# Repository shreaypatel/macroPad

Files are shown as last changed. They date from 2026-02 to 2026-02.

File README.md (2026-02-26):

This repository contains the relevant documentation for my custom macropad project. I designed this macropad to be slim, portable and minimalist to match my use case needs. I will primarily use it for onshape CAD shortcuts, 
but I am looking to explore setting up a different mode on it for KiCad shortcuts. The macropad connects to a computer via usb c. I began my design process with the wiring of the schematic. Here I opted for a 3x2 keyboard matrix 
to set up the switch connections. This takes up less input connections on the microcontroller while allowing me to customize 6 individual cherry mx switches. Next, I connected the diodes in between the switches to prevent keyboard
ghosting. Lastly, I set up a rotary rotary encoder switch for the zoom function on onshape CAD. This is the **CAD onshape source file (https://cad.onshape.com/documents/c0725aa56d0443495cbb7afd/w/927aa1fb6a4206026ca4e494/e/48b73c10d6aff836ede0c6ac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)**



With the schematic complete I moved onto routing the connections on the actual pcb. I also 
organized the layout of the pcb at this stage and ensured that all connections were wired up properly. 





With the elctrical side of things completed I moved onto desiging the 3D printed enclosure for the macropad. Here I built a minimalistic case with cutouts for the switches and rotary encoder switch. I also created a cutout for the USB C connection
port. Notably, I decided to forgo using screws to secure the top and bottom parts of the enclosure. Instead I opted for a press fit conneciton with 4 3D printed studs that connect directly to the top part of the case. These slot into a square shaped
hole in the bottom of the case. This makes the prototyping process easier and allows me to qucikly clean the internals of the macropad if need be. I applied a chamfer to the 4 studs to ensure they smoothly slot into the bottom of the case. I also included 
an elevated platform support for the pcb to rest on in the enclosure. Superglue can also be used to more securely attach the pins into their respective holes. 





This concludes my design process. Overall, I had a lot of fun making this project and I would say my favourite part was learning how to use KiCad to design PCBs for the first time. 

**BOM:**

* 1 x 3D printed case
* 1 x SEEED XIAO RP2040
* 4 x CHERRY MX keyswitches
* 1 x EC11 rotary encoder
* 6 x 1N4148 diodes

Final Image of CAD and electronics together: 


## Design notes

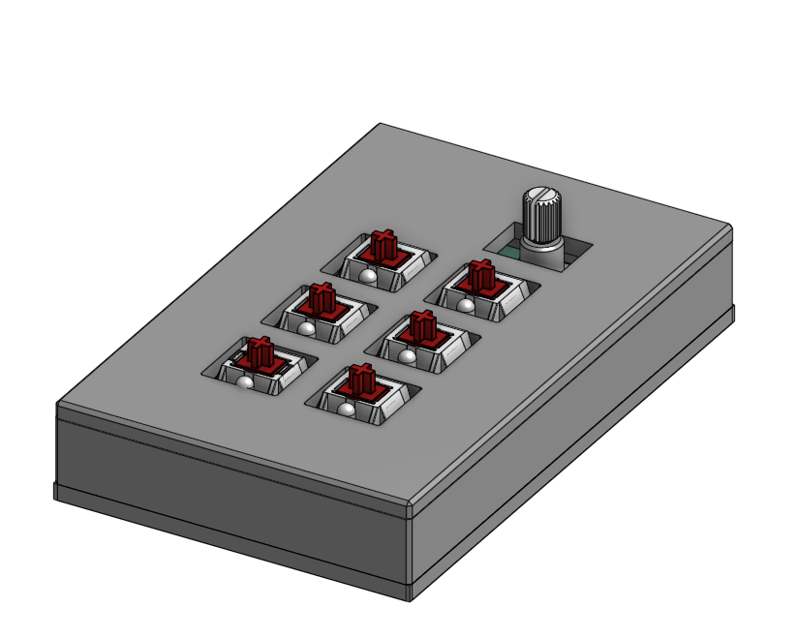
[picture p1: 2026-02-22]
CADwElectronics.png

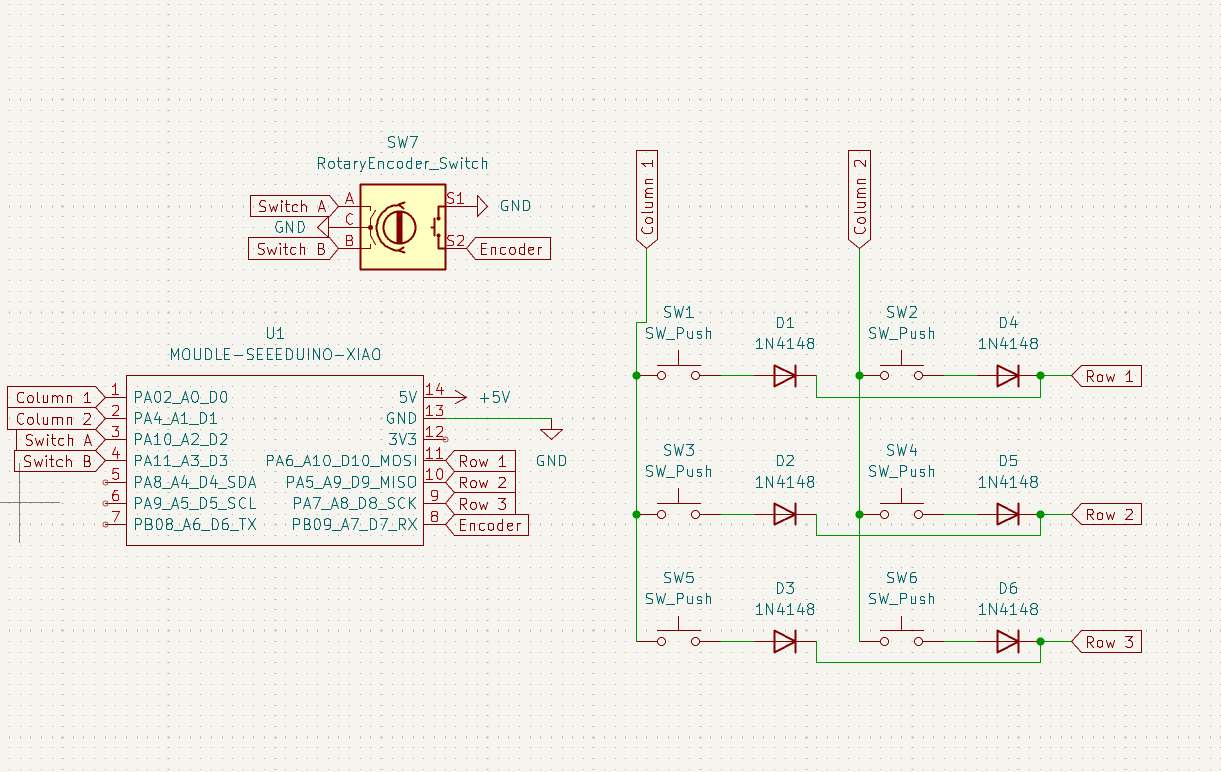
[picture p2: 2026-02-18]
PCB/schematicDrawingAngle1.png

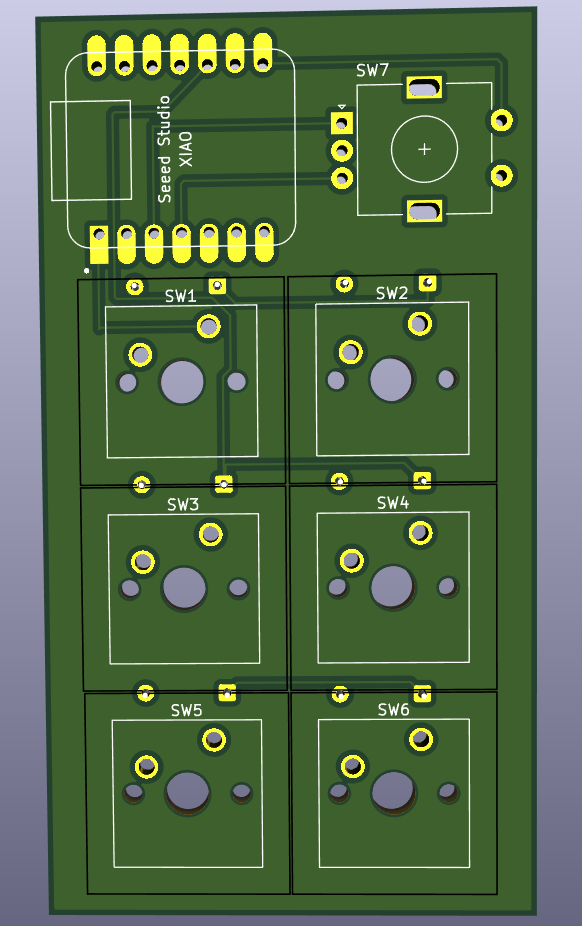
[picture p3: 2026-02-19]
PCB/pcb3dAngle_1.png

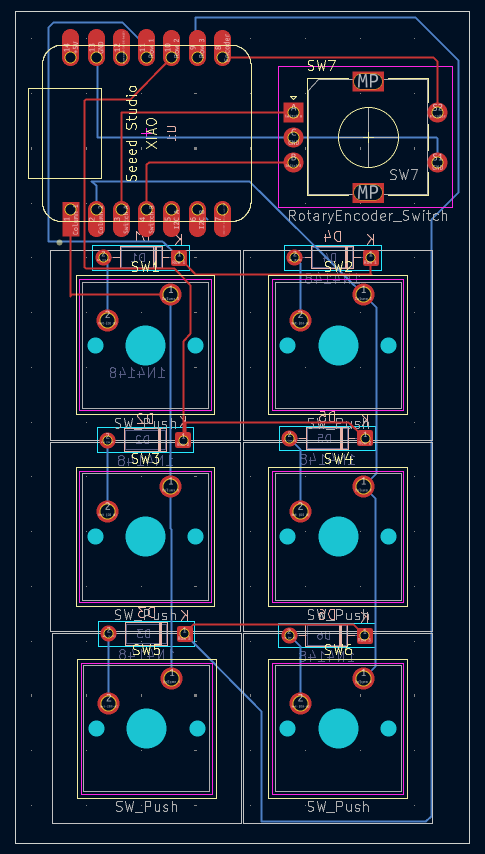
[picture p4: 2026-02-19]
PCB/pcb2dAngle1.png

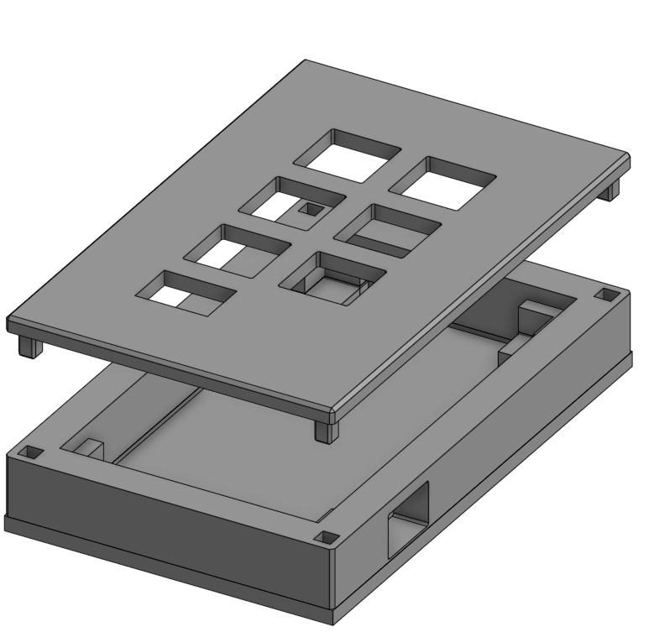
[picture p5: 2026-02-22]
CAD/mpAngle4.png

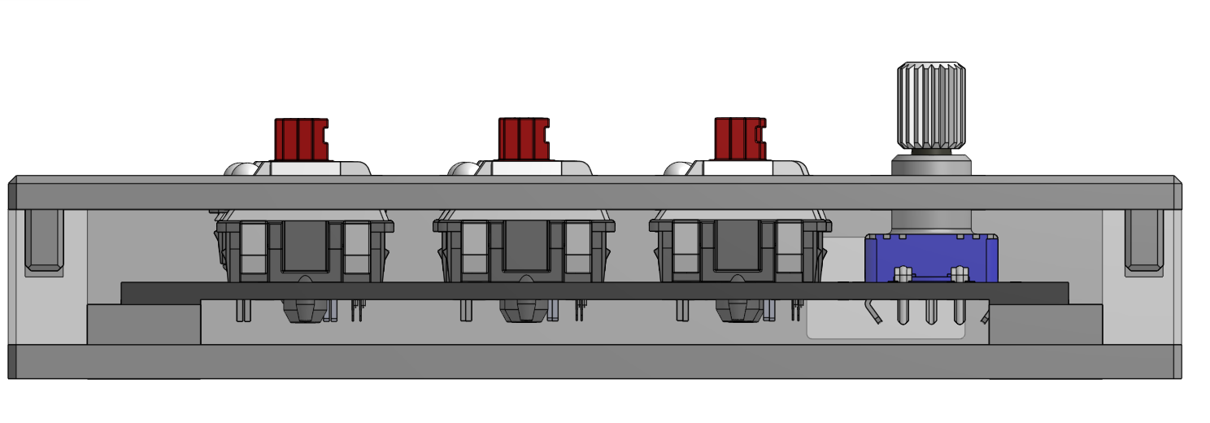
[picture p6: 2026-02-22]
CAD/mpAngle2.png

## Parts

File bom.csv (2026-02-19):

Designator | Footprint | Quantity | Value | LCSC Part #
D1, D2, D3, D4, D5, D6 | D_DO-35_SOD27_P7.62mm_Horizontal | 6 | 1N4148
SW1, SW2, SW3, SW4, SW5, SW6 | SW_Cherry_MX_1.00u_PCB | 6 | SW_Push
SW7 | RotaryEncoder_Alps_EC11E-Switch_Vertical_H20mm | 1 | RotaryEncoder_Switch
U1 | XIAO-Generic-Hybrid-14P-2.54-21X17.8MM | 1 | MOUDLE-SEEEDUINO-XIAO

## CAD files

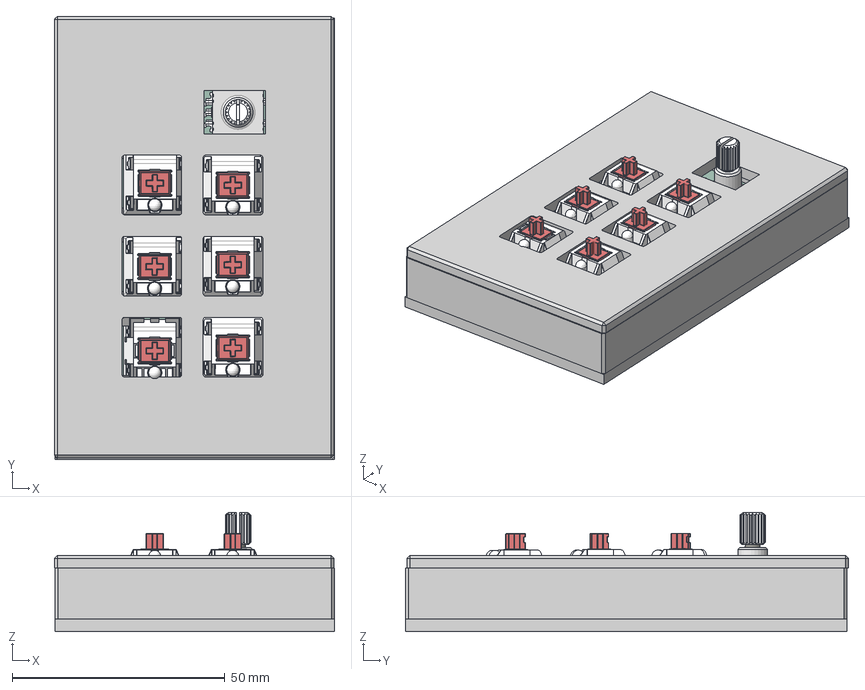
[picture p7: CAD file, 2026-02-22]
FullCADwElec.step
65.9 x 104.1 x 28.0 mm
Led 3mm_trans x 12
Pulsador x 6
Pin2 x 6
Pin1 x 6
Pieza5^Cherry MX x 6
��ת������EC11E-05SW
Bottom x 6
Top x 6
spMacropad_PCB

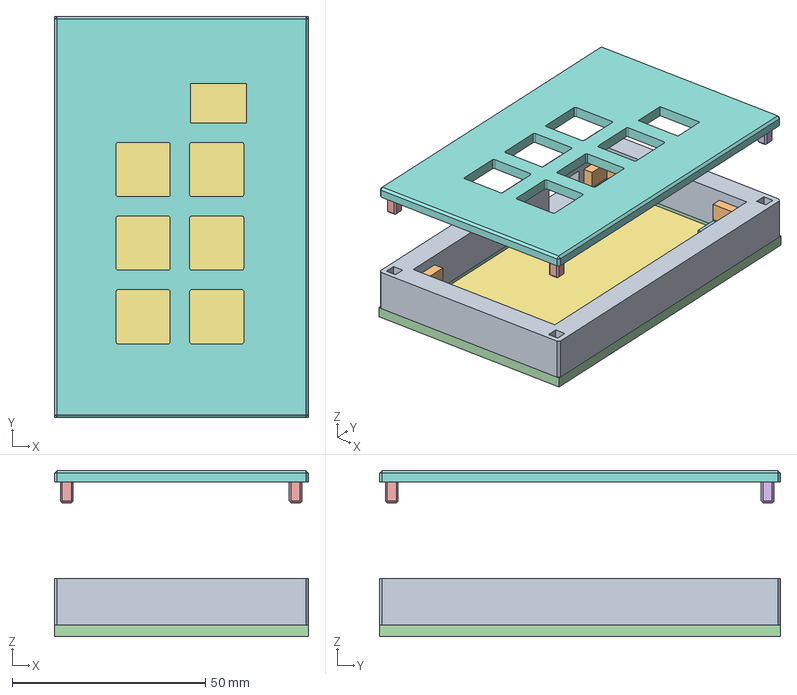
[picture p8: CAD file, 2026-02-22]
CAD/fullCoverCase.step
65.7 x 103.8 x 43.0 mm

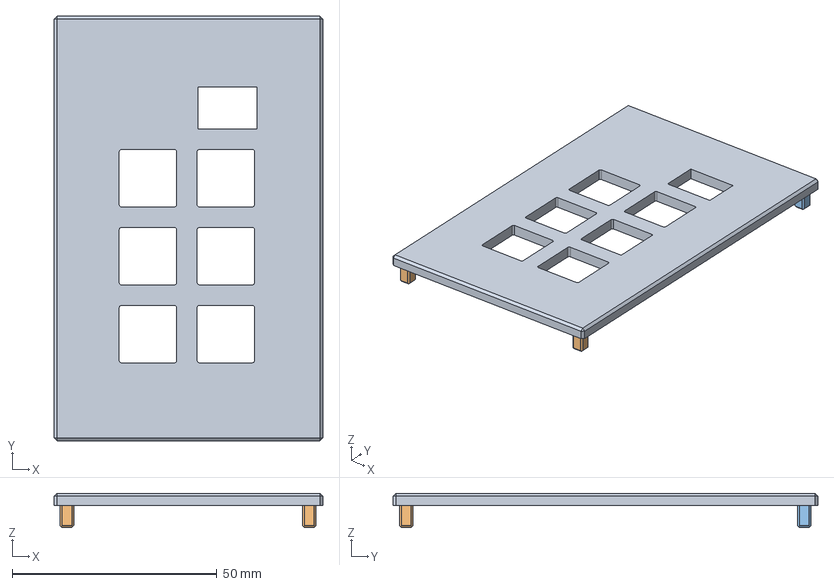
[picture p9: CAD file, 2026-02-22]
CAD/topCaseOnly.step
65.7 x 103.8 x 8.40 mm

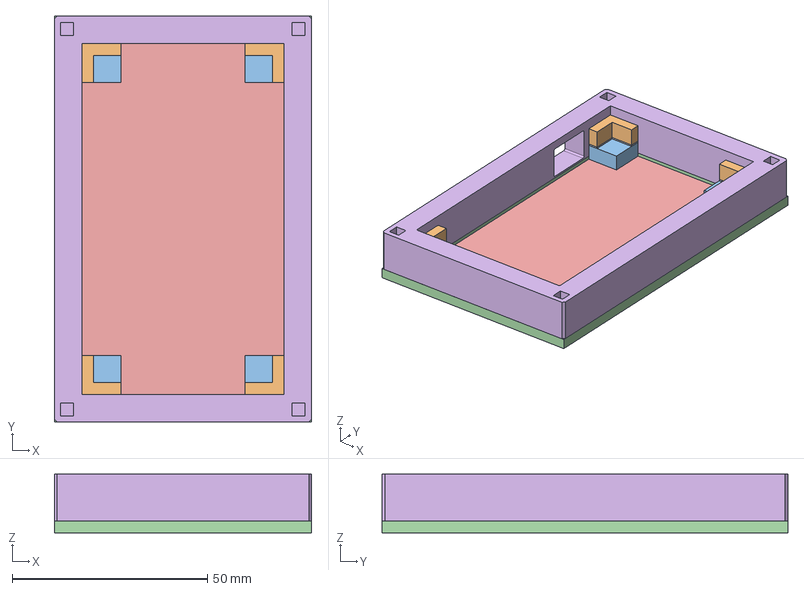
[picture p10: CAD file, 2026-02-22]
CAD/bottomCaseOnly.step
65.7 x 103.8 x 15.0 mm

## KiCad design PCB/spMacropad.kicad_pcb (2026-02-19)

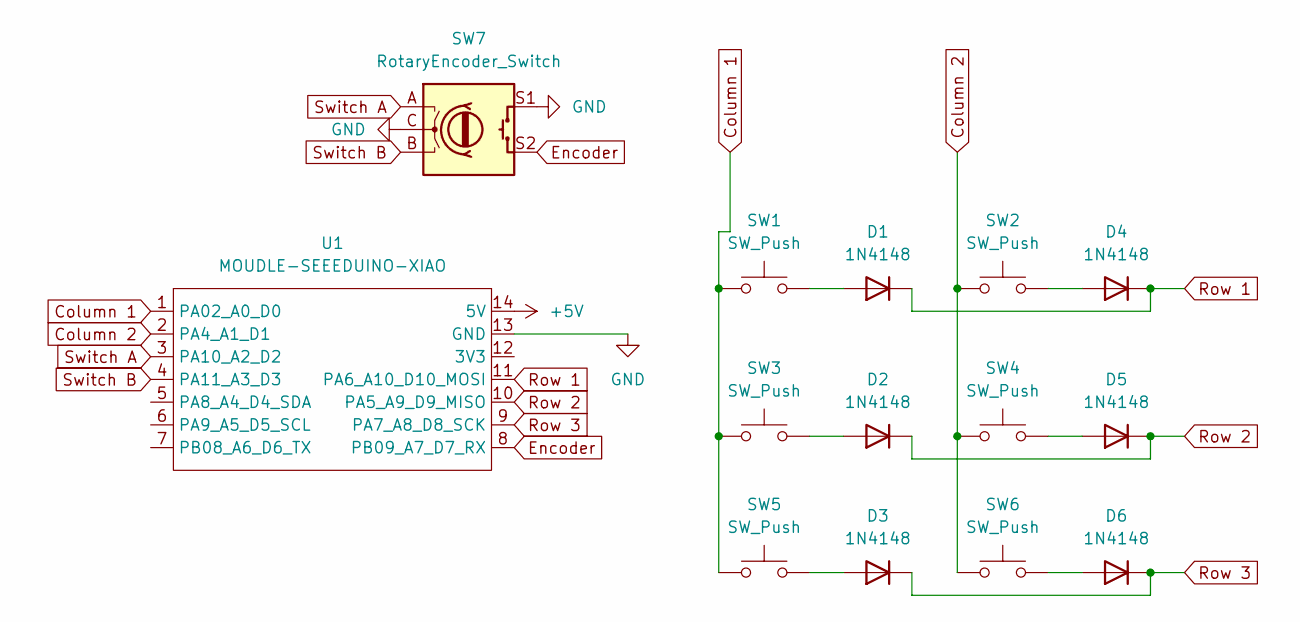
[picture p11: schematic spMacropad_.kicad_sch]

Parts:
D1, D2, D3, D4, D5, D6: 1N4148; D_DO-35_SOD27_P7.62mm_Horizontal
SW1, SW2, SW3, SW4, SW5, SW6: SW_Push; SW_Cherry_MX_1.00u_PCB
SW7: RotaryEncoder_Switch; RotaryEncoder_Alps_EC11E-Switch_Vertical_H20mm
U1: MOUDLE-SEEEDUINO-XIAO; XIAO-Generic-Hybrid-14P-2.54-21X17.8MM

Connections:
+5V: U1.14 (5V)
Column 1: SW1.1, SW3.1, SW5.1, U1.1 (PA02_A0_D0)
Column 2: SW2.1, SW4.1, SW6.1, U1.2 (PA4_A1_D1)
Encoder: SW7.S2, U1.8 (PB09_A7_D7_RX)
GND: SW7.C, SW7.S1, U1.13 (GND)
I2C A: U1.5 (PA8_A4_D4_SDA)
I2C B: U1.6 (PA9_A5_D5_SCL)
unnamed: D1.2 (A), SW1.2
unnamed: D2.2 (A), SW3.2
unnamed: D3.2 (A), SW5.2
unnamed: D4.2 (A), SW2.2
unnamed: D5.2 (A), SW4.2
unnamed: D6.2 (A), SW6.2
Row 1: D1.1 (K), D4.1 (K), U1.11 (PA6_A10_D10_MOSI)
Row 2: D2.1 (K), D5.1 (K), U1.10 (PA5_A9_D9_MISO)
Row 3: D3.1 (K), D6.1 (K), U1.9 (PA7_A8_D8_SCK)
Switch A: SW7.A, U1.3 (PA10_A2_D2)
Switch B: SW7.B, U1.4 (PA11_A3_D3)

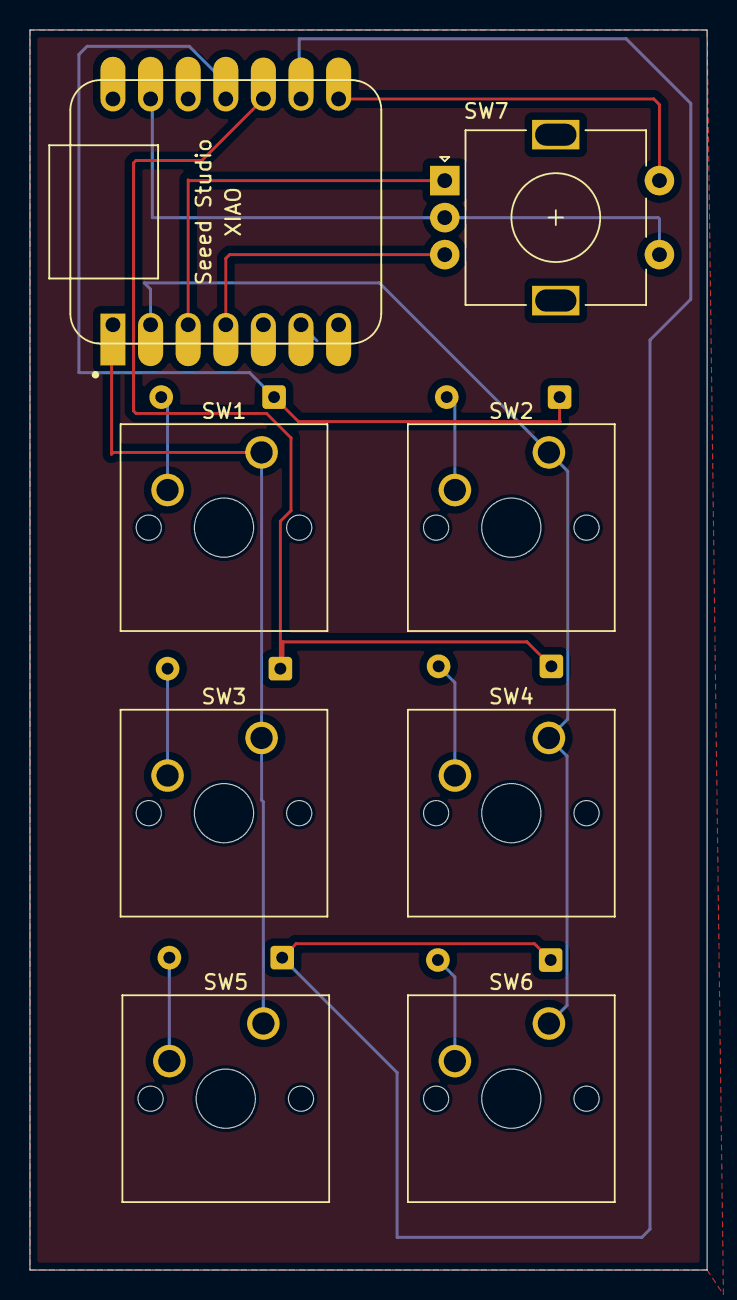
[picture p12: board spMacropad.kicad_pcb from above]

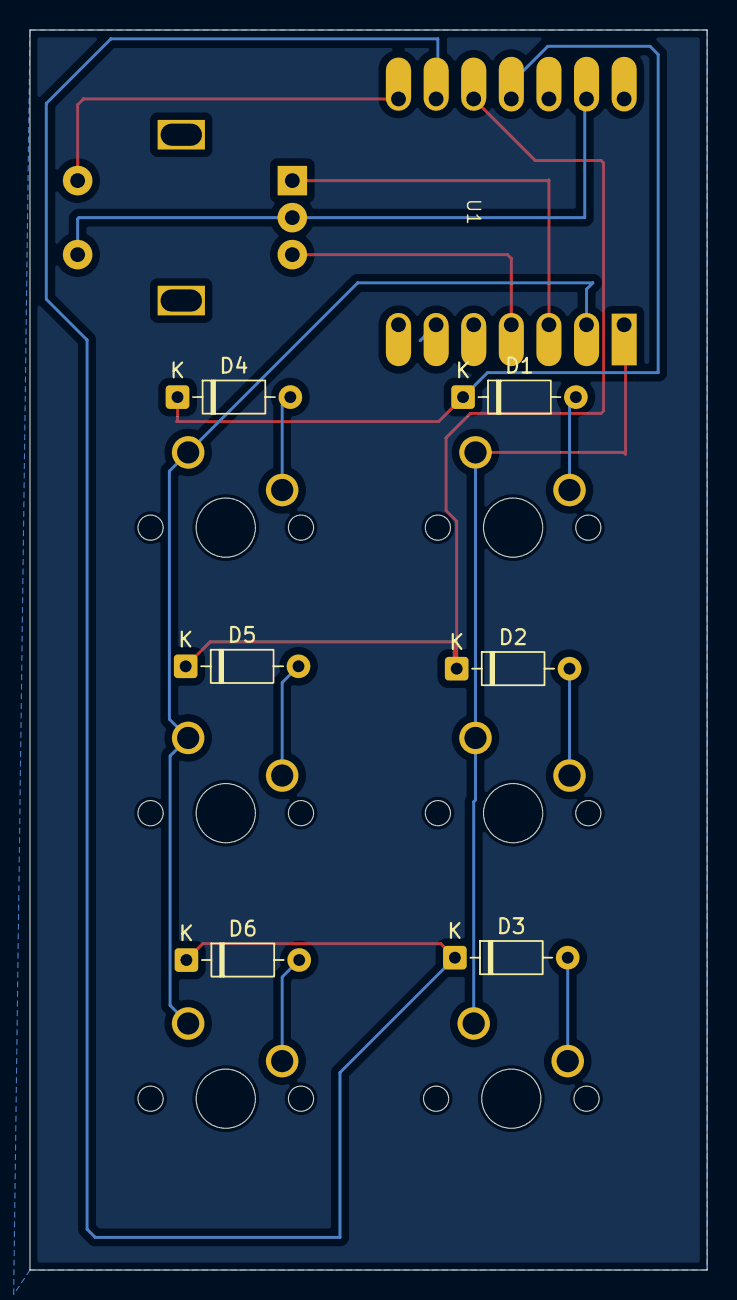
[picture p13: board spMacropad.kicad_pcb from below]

Board: 2 copper layers, 45.7 x 83.8 mm, 14 parts (6 on the bottom side), 15 nets.

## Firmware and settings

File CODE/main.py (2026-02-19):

import board
import digitalio
import rotaryio
import usb_hid
import time
from adafruit_hid.keyboard import Keyboard
from adafruit_hid.keycode import Keycode
from adafruit_hid.mouse import Mouse

# ==========================================
# 1. SETUP & CONFIGURATION
# ==========================================

# Initialize USB HID devices
keyboard = Keyboard(usb_hid.devices)
mouse = Mouse(usb_hid.devices)

# Setup Rotary Encoder (Pins D2 & D3 from your schematic)
encoder = rotaryio.IncrementalEncoder(board.D2, board.D3)
last_position = encoder.position

# Setup Encoder Push Button (Pin D6 from your schematic)
encoder_btn = digitalio.DigitalInOut(board.D6)
encoder_btn.direction = digitalio.Direction.INPUT
encoder_btn.pull = digitalio.Pull.UP

# Setup Matrix Pins (Matches KiCad layout)
COL_PINS = (board.D0, board.D1)
ROW_PINS = (board.D10, board.D9, board.D8)

cols = []
for pin in COL_PINS:
    c = digitalio.DigitalInOut(pin)
    c.direction = digitalio.Direction.OUTPUT
    c.value = False # Rest state is LOW
    cols.append(c)

rows = []
for pin in ROW_PINS:
    r = digitalio.DigitalInOut(pin)
    r.direction = digitalio.Direction.INPUT
    r.pull = digitalio.Pull.DOWN # Pull down to ground. Reads HIGH when pressed.
    rows.append(r)

# ==========================================
# 2. KEYMAP (Onshape CAD Shortcuts)
# ==========================================
# Map the hardware coordinates (Column, Row) to the desired keycodes.
# Note: Onshape uses combinations for some of these. You can customize the ALT/SHIFT combos 
# to match your specific Onshape account preferences.

KEYMAP = {
    (0, 0): [Keycode.P],                                # SW1: New Sketch Plane
    (1, 0): [Keycode.SHIFT, Keycode.S],                 # SW2: New Sketch
    (0, 1): [Keycode.ALT, Keycode.P],                   # SW3: New Part Studio (Custom map)
    (1, 1): [Keycode.ALT, Keycode.A],                   # SW4: New Assembly (Custom map)
    (0, 2): [Keycode.SHIFT, Keycode.E],                 # SW5: New Extrude
    (1, 2): [Keycode.ALT, Keycode.N],                   # SW6: New Document (Custom map)
}

pressed_keys = set()

# ==========================================
# 3. MAIN LOOP
# ==========================================

while True:
    # --- A. Handle Rotary Encoder (Zoom via Mouse Scroll) ---
    current_position = encoder.position
    if current_position != last_position:
        delta = current_position - last_position
        # Onshape uses the mouse scroll wheel to zoom
        mouse.move(wheel=delta)
        last_position = current_position
        
    # --- B. Handle Encoder Button ---
    # Optional: You can assign a function to the encoder click here
    if not encoder_btn.value:
        pass # Add an action if you want a click function later

    # --- C. Scan the Mechanical Switches ---
    current_presses = set()
    
    # Energize one column at a time
    for c_idx, col in enumerate(cols):
        col.value = True # Drive HIGH
        
        # Check which rows are receiving current
        for r_idx, row in enumerate(rows):
            if row.value: # If HIGH, the switch is pressed
                current_presses.add((c_idx, r_idx))
                
        col.value = False # Reset LOW
        
    # Send KeyPress events for newly pressed switches
    for key in current_presses - pressed_keys:
        if key in KEYMAP:
            keyboard.press(*KEYMAP[key])
            
    # Send KeyRelease events for newly released switches
    for key in pressed_keys - current_presses:
        if key in KEYMAP:
            keyboard.release(*KEYMAP[key])
            
    # Update state and debounce
    pressed_keys = current_presses
    time.sleep(0.01)
